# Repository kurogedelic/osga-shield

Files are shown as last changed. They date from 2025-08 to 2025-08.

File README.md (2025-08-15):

# osga-shield

mock

An open hardware platform for creative coding and generative art, designed to work with the [OSGA software platform](https://github.com/kurogedelic/osga).

## Project Structure

```
osga-shield/
├── CLAUDE.md              # Complete setup guide and troubleshooting
├── PROJECT_STRUCTURE.md   # Detailed project organization
├── firmware/              # Raspberry Pi OS configuration and software
│   ├── install.sh        # Complete installation script
│   ├── boot/             # Boot configuration files
│   ├── config/           # System configurations (ALSA, Grove I2C)
│   ├── scripts/          # Hardware initialization scripts
│   └── systemd/          # Auto-start service definitions
├── hardware/              # Hardware design files
│   ├── kicad/            # KiCad schematic and PCB layout
│   ├── bom/              # Bill of Materials
│   ├── fabrication/      # Gerber files for PCB manufacturing
│   └── 3d-models/        # 3D models for enclosure
└── README.md             # This file - project overview
```

📋 See [PROJECT_STRUCTURE.md](PROJECT_STRUCTURE.md) for detailed organization guide.  
🔧 See [CLAUDE.md](CLAUDE.md) for complete setup instructions and troubleshooting.

## Overview

osga-shield is a Raspberry Pi shield that provides a complete hardware interface for audio-visual creative applications. It features physical controls, motion sensing, environmental monitoring, and high-quality audio output.

## Hardware Architecture

```mermaid
graph TD
  RPI["RPi Zero 2 W"]

  subgraph INPUTS
    BTN_A["Button A"]
    BTN_B["Button B"]
    BTN_C["Button C"]
    BTN_R["Rotary Button"]
    ENC["Rotary Encoder"]
    MPU["MPU6050 (Gyro + Accel)"]
    BME["BME280 (Temp / Hum / Pressure)"]
  end

  subgraph OUTPUTS
    DISP["ILI9341 (320x240 SPI LCD)"]
    DAC["PCM5102 (I2S DAC)"]
    SPK["Speaker"]
    HAPTIC["Piezo Haptic"]
  end

  BTN_A --> RPI
  BTN_B --> RPI
  BTN_C --> RPI
  BTN_R --> RPI
  ENC --> RPI
  MPU --> RPI
  BME --> RPI

  RPI --> DISP
  RPI --> DAC
  DAC --> SPK
  RPI --> HAPTIC
```

## Specifications

### Display
- **Controller**: ILI9341
- **Resolution**: 320x240 pixels
- **Interface**: SPI
- **Color**: 16-bit RGB

### Audio
- **DAC**: PCM5102A (I2S)
- **Output**: 3.5mm stereo jack + built-in speaker
- **Sample Rate**: Up to 384kHz
- **Bit Depth**: 32-bit

### Input Controls
- **Buttons**: 2x tactile switches (A, B)
- **Rotary Encoder**: With push button function (Enter)
- **Motion**: MPU6050 6-axis IMU (3-axis gyro + 3-axis accelerometer)

### Expansion
- **Grove Connector**: I²C expansion port for additional sensors/modules
  - Compatible with Seeed Studio Grove ecosystem
  - 3.3V/5V power selectable

### Feedback
- **Haptic**: Piezo element for tactile feedback
- **Visual**: SPI LCD display

### Processing
- **Platform**: Raspberry Pi Zero 2 W
- **Connectivity**: WiFi, Bluetooth

## Pin Mapping (Raspberry Pi Zero 2 WH)

### I²C Buses
| Bus | Component | GPIO Pin | Physical Pin | Function |
|-----|---|---|---|---|
| I²C1 | MPU_SDA | GPIO 2 | Pin 3 | MPU6050 Data |
| I²C1 | MPU_SCL | GPIO 3 | Pin 5 | MPU6050 Clock |
| I²C (SW) | Grove_SDA | GPIO 22 | Pin 15 | Grove Connector Data |
| I²C (SW) | Grove_SCL | GPIO 23 | Pin 16 | Grove Connector Clock |

### Audio (I²S)
| Component | GPIO Pin | Physical Pin | Function |
|---|---|---|---|
| I2S_BCK | GPIO 18 | Pin 12 | Bit Clock |
| I2S_LRCK | GPIO 19 | Pin 35 | Left/Right Clock |
| I2S_IN | GPIO 20 | Pin 38 | Audio Input |
| I2S_OUT | GPIO 21 | Pin 40 | Audio Output (to PCM5102) |

### Display (SPI)
| Component | GPIO Pin | Physical Pin | Function |
|---|---|---|---|
| LCD_CS | GPIO 8 (CE0) | Pin 24 | Chip Select |
| LCD_MISO | GPIO 9 | Pin 21 | Master In Slave Out |
| LCD_MOSI | GPIO 10 | Pin 19 | Master Out Slave In |
| LCD_SCLK | GPIO 11 | Pin 23 | Serial Clock |
| LCD_DC | GPIO 24 | Pin 18 | Data/Command |
| LCD_RESET | GPIO 25 | Pin 22 | Reset |
| LCD_LED | GPIO 12 | Pin 32 | Backlight PWM |

### Input Controls
| Component | GPIO Pin | Physical Pin | Function |
|---|---|---|---|
| Button_A | GPIO 6 | Pin 31 | Button A |
| Button_B | GPIO 5 | Pin 29 | Button B |
| Rotary_CLK | GPIO 16 | Pin 36 | Encoder Clock |
| Rotary_DT | GPIO 13 | Pin 33 | Encoder Data |
| Rotary_Enter | GPIO 26 | Pin 37 | Encoder Button |

### UART (Debug)
| Component | GPIO Pin | Physical Pin | Function |
|---|---|---|---|
| UART_TX | GPIO 14 | Pin 8 | Transmit |
| UART_RX | GPIO 15 | Pin 10 | Receive |

## Software Support

The osga-shield is designed to work seamlessly with:
- **[OSGA](https://github.com/kurogedelic/osga)**: Open Sound & Graphics Appliance platform
- **Raspberry Pi OS**: Standard Linux support
- **Love2D**: For creative coding applications
- **Python**: Via GPIO and device libraries

## Getting Started

1. **Hardware Assembly**
   - Mount the shield on a Raspberry Pi Zero 2 W
   - Connect speaker or headphones to audio output
   - Power via micro USB

2. **Software Installation**
   ```bash
   # Flash Raspberry Pi OS Lite to SD card
   # Boot the Pi and clone this repository
   git clone https://github.com/kurogedelic/osga-shield.git
   cd osga-shield/firmware
   
   # Run installation script
   sudo ./install.sh
   
   # System will reboot and start OSGA automatically
   ```

3. **Test Hardware**
   - Run the hardware test app from OSGA launcher
   - Verify all buttons, encoder, and sensors work

## Development

### Creating Apps
See the [OSGA documentation](https://github.com/kurogedelic/osga#creating-an-app) for app development guidelines.

### Hardware Libraries
- **Python**: Use `RPi.GPIO`, `smbus2` for I2C devices
- **C/C++**: Use `wiringPi` or direct register access
- **Love2D**: Via OSGA's hardware abstraction layer

## License

This hardware design is open source. Schematics and PCB designs will be released under:
- **Hardware**: CERN Open Hardware License v2
- **Software**: LGPL v3 (matching OSGA platform)

## Credits

Designed by Leo Kuroshita from Hugelton Instruments (2025)

## Contributing

Contributions are welcome! Please submit issues and pull requests for:
- Hardware improvements
- Documentation updates
- Example projects
- Bug fixes

## Related Projects

- **[OSGA](https://github.com/kurogedelic/osga)**: The software platform
- **[osga-apps](https://github.com/kurogedelic/osga-apps)**: Community-contributed applications

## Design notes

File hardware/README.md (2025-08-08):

# OSGA Shield Hardware

## Directory Structure

- **kicad/** - KiCad project files (schematic, PCB layout)
- **bom/** - Bill of Materials and component specifications
- **fabrication/** - Gerber files and fabrication outputs
- **3d-models/** - 3D models for enclosure and mechanical design

## Hardware Revision

Current Version: v1.0

## License

Hardware designs are released under CERN Open Hardware License v2

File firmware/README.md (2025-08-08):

# OSGA Shield Firmware

## Directory Structure

- **boot/** - Raspberry Pi boot configuration files
- **config/** - System configuration files (ALSA, etc.)
- **scripts/** - Initialization and utility scripts  
- **systemd/** - SystemD service definitions
- **install.sh** - Main installation script

## Installation

1. Flash Raspberry Pi OS Lite to SD card
2. Clone this repository on the Pi
3. Run installation script:
   ```bash
   cd firmware
   sudo ./install.sh
   ```
4. Reboot

## Configuration

The system runs in headless mode with:
- Direct framebuffer access via DRM/KMS
- I2S audio output
- Automatic OSGA startup on boot
- No X11/desktop environment

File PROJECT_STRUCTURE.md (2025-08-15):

# OSGA Shield Project Structure

## Directory Organization

```
osga-shield/
├── CLAUDE.md                 # Setup documentation and troubleshooting guide
├── README.md                 # Project overview and pin mappings
├── PROJECT_STRUCTURE.md      # This file - project organization guide
├── firmware/                 # Raspberry Pi OS configuration and software
│   ├── README.md            # Firmware installation guide
│   ├── install.sh           # Complete installation script
│   ├── boot/                # Boot configuration files
│   │   ├── config.txt       # Hardware configuration for Pi
│   │   └── cmdline.txt      # Kernel command line parameters
│   ├── config/              # System configuration files
│   │   ├── asound.conf      # ALSA audio configuration for PCM5102
│   │   └── grove-i2c.conf   # Grove connector I2C bus settings
│   ├── scripts/             # System initialization scripts
│   │   ├── grove-i2c-setup.sh   # Software I2C setup for Grove
│   │   ├── osga-init.sh     # Hardware initialization script
│   │   └── osga-splash      # Boot splash screen script
│   └── systemd/             # SystemD service definitions
│       ├── osga.service     # Main OSGA auto-start service
│       └── osga-early.service   # Early boot display service
└── hardware/                # Hardware design files
    ├── README.md            # Hardware documentation
    ├── kicad/               # KiCad PCB design files
    │   ├── osga.kicad_pro   # Main project file
    │   ├── osga.kicad_sch   # Schematic design
    │   ├── osga.kicad_pcb   # PCB layout
    │   └── *.kicad_sym      # Symbol libraries
    ├── bom/                 # Bill of Materials
    ├── fabrication/         # Gerber files for PCB manufacturing
    └── 3d-models/           # 3D models for enclosure design
```

## Key Components

### Firmware (Software)
- **Raspberry Pi OS Lite** - Minimal OS without desktop environment
- **OSGA Runtime** - Creative coding platform via Love2D
- **SystemD Services** - Auto-start configuration
- **Hardware Drivers** - I2S audio, SPI display, I2C sensors

### Hardware Design
- **KiCad Project** - Complete PCB design files
- **Manufacturing Files** - Ready for PCB fabrication
- **Component Lists** - BOM for assembly

## Usage

### For Users (Installation)
1. Flash Raspberry Pi OS Lite to SD card
2. Clone this repository on the Pi
3. Run `firmware/install.sh` as root
4. System will auto-configure and start OSGA

### For Developers (Hardware)
1. Open `hardware/kicad/osga.kicad_pro` in KiCad
2. Modify schematic and PCB as needed
3. Export gerber files to `hardware/fabrication/`
4. Update BOM in `hardware/bom/`

### For Documentation
- **CLAUDE.md** - Complete setup guide and troubleshooting
- **README.md** - Quick overview and pin mappings
- **firmware/README.md** - Software installation details
- **hardware/README.md** - Hardware specifications

## Version Control
- All design files are version controlled
- KiCad libraries included in repository
- Firmware scripts tested on Raspberry Pi Zero 2 W
- Documentation updated with each hardware revision

## License
- **Hardware**: CERN Open Hardware License v2
- **Software**: LGPL v3 (matching OSGA platform)

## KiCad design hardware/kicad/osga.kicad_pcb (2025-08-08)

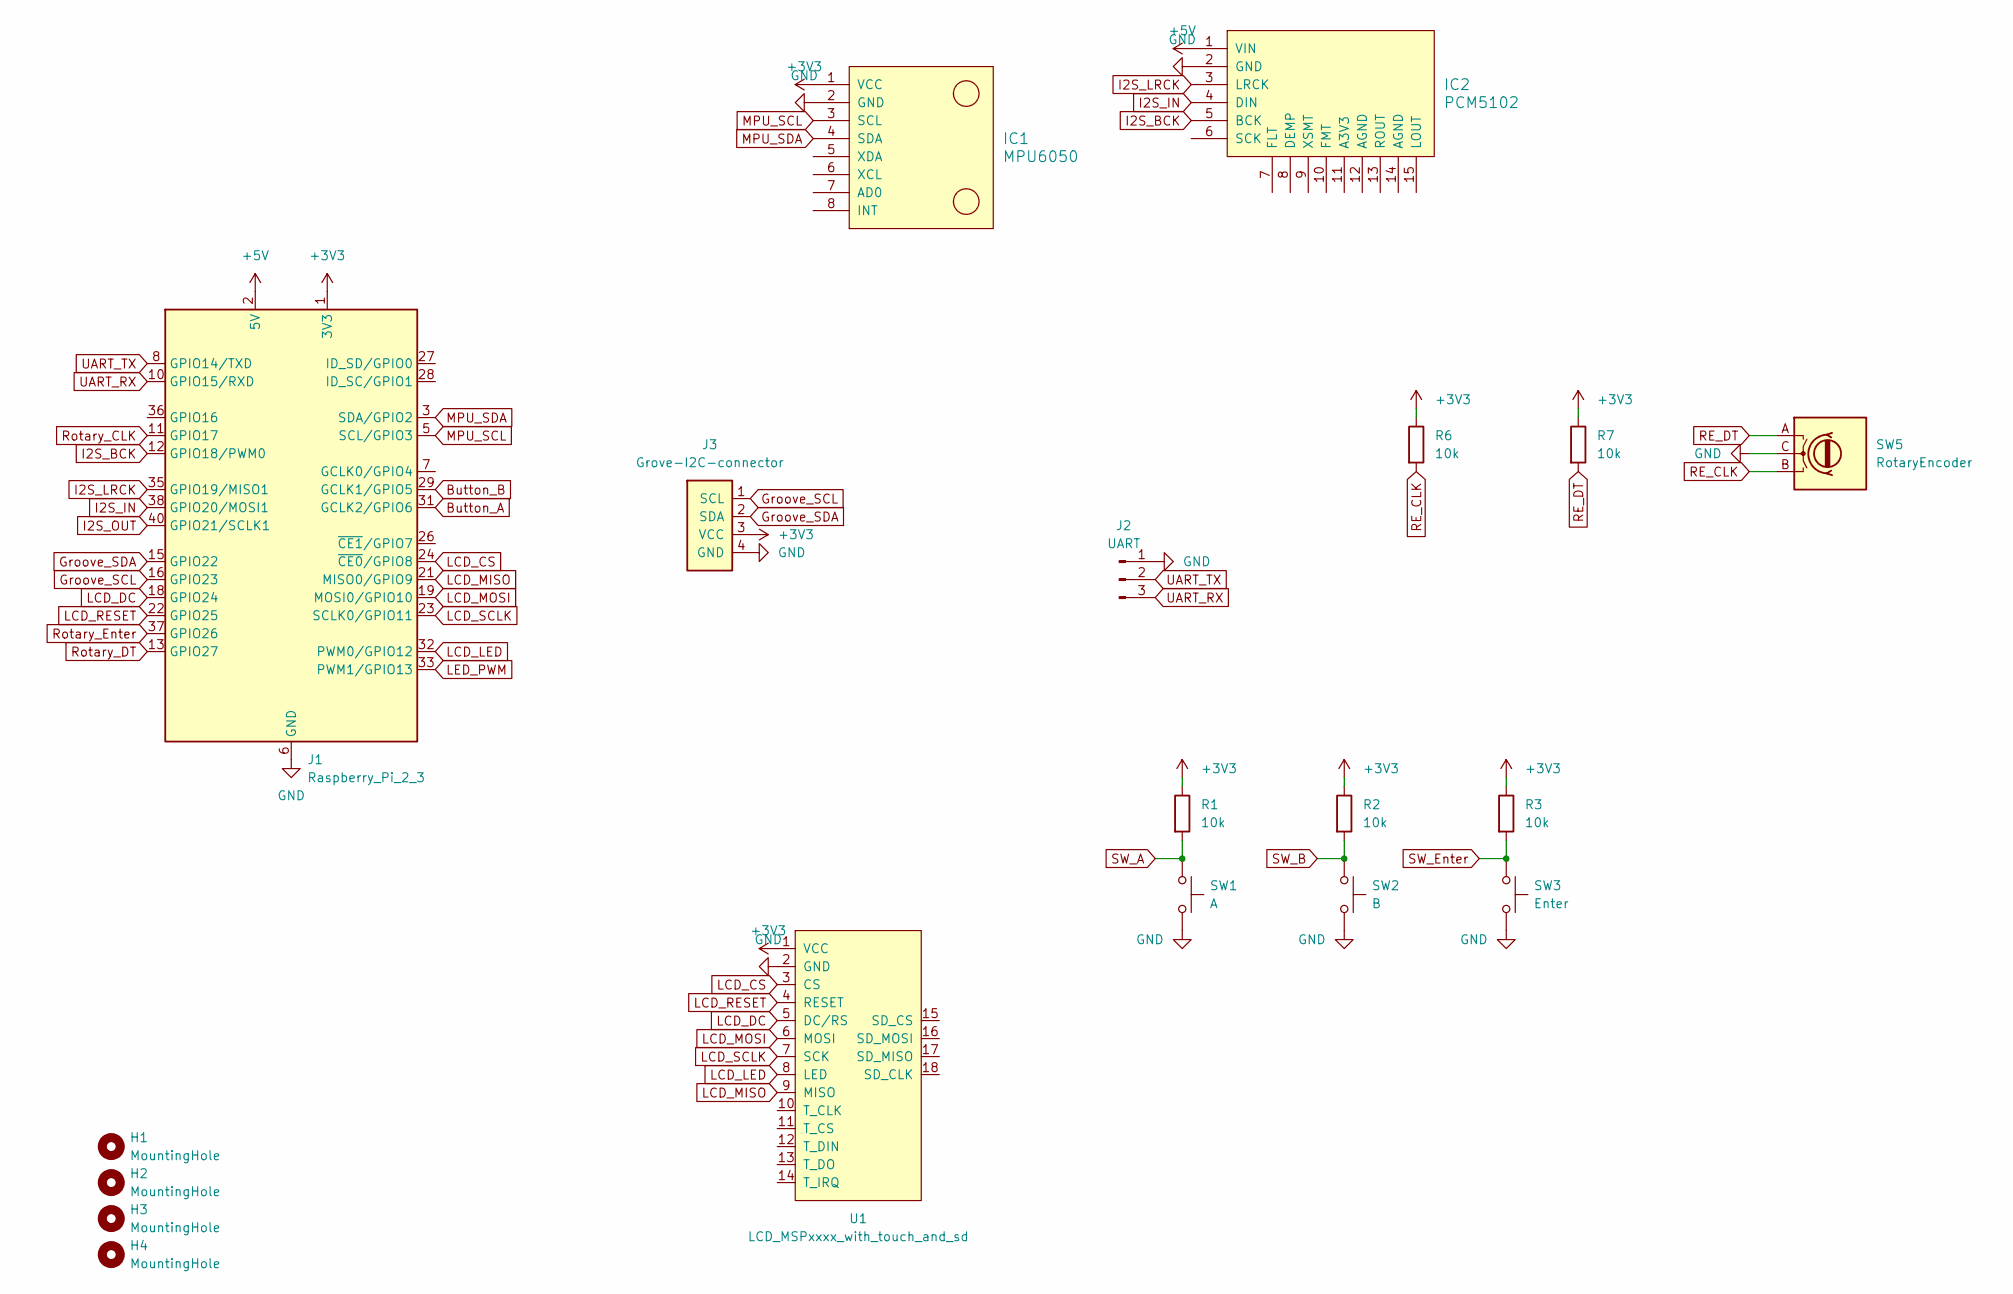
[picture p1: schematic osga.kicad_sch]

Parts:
H1, H2, H3, H4: MountingHole; Mounting_Wuerth_WA-SMSI-M2_H1mm_9774010243
IC1: MPU6050
IC2: PCM5102; PCM5102_flipped
J1: Raspberry_Pi_2_3; Raspberry_Pi_Header
J2: UART; PinSocket_1x03_P2.54mm_Horizontal
J3: Grove-I2C-connector; NS-Tech_Grove_1x04_P2mm_Vertical
R1, R2, R3, R6, R7: 10k; R_Axial_DIN0207_L6.3mm_D2.5mm_P10.16mm_Horizontal
SW1: A; SW_Redragon_LowProfile_PCB_1.00u
SW2: B; SW_Redragon_LowProfile_PCB_1.00u
SW3: Enter; SW_Redragon_LowProfile_PCB_1.00u
SW5: RotaryEncoder; RotaryEncoder_Alps_EC12E_Vertical_H20mm
U1: LCD_MSPxxxx_with_touch_and_sd; ili9341_2.4inch

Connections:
+3V3: IC1.1 (VCC), J1.1 (3V3), J1.17 (3V3), J3.3 (VCC), R1.1, R2.1, R3.1, R6.1, R7.1, U1.1 (VCC)
+5V: IC2.1 (VIN), J1.2 (5V), J1.4 (5V)
Button_A: J1.31 (GCLK2/GPIO6)
Button_B: J1.29 (GCLK1/GPIO5)
GND: IC1.2 (GND), IC2.2 (GND), J1.6 (GND), J1.9 (GND), J1.14 (GND), J1.20 (GND), J1.25 (GND), J1.30 (GND), J1.34 (GND), J1.39 (GND), J2.1, J3.4 (GND), SW1.2, SW2.2, SW3.2, SW5.C, U1.2 (GND)
Groove_SCL: J1.16 (GPIO23), J3.1 (SCL)
Groove_SDA: J1.15 (GPIO22), J3.2 (SDA)
I2S_BCK: IC2.5 (BCK), J1.12 (GPIO18/PWM0)
I2S_IN: IC2.4 (DIN), J1.38 (GPIO20/MOSI1)
I2S_LRCK: IC2.3 (LRCK), J1.35 (GPIO19/MISO1)
I2S_OUT: J1.40 (GPIO21/SCLK1)
LCD_CS: J1.24 (~CE0/GPIO8), U1.3 (CS)
LCD_DC: J1.18 (GPIO24), U1.5 (DC/RS)
LCD_LED: J1.32 (PWM0/GPIO12), U1.8 (LED)
LCD_MISO: J1.21 (MISO0/GPIO9), U1.9 (MISO)
LCD_MOSI: J1.19 (MOSI0/GPIO10), U1.6 (MOSI)
LCD_RESET: J1.22 (GPIO25), U1.4 (RESET)
LCD_SCLK: J1.23 (SCLK0/GPIO11), U1.7 (SCK)
LED_PWM: J1.33 (PWM1/GPIO13)
MPU_SCL: IC1.3 (SCL), J1.5 (SCL/GPIO3)
MPU_SDA: IC1.4 (SDA), J1.3 (SDA/GPIO2)
RE_CLK: R6.2, SW5.B
RE_DT: R7.2, SW5.A
Rotary_CLK: J1.11 (GPIO17)
Rotary_DT: J1.13 (GPIO27)
Rotary_Enter: J1.37 (GPIO26)
SW_A: R1.2, SW1.1
SW_B: R2.2, SW2.1
SW_Enter: R3.2, SW3.1
UART_RX: J1.10 (GPIO15/RXD), J2.3
UART_TX: J1.8 (GPIO14/TXD), J2.2

Board: 2 copper layers, 19 parts (2 on the bottom side), 24 nets, no tracks yet.

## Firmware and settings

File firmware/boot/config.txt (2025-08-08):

# OSGA Shield Boot Configuration
# Raspberry Pi Zero 2 W - Minimal Boot Setup

# GPU Memory (minimum needed for framebuffer)
gpu_mem=16

# Disable unnecessary interfaces
dtparam=audio=off
enable_uart=0

# Enable I2C1 for MPU6050
dtparam=i2c_arm=on
dtparam=i2c_baudrate=400000

# Software I2C for Grove connector (GPIO22/23)
# Will be configured via device tree overlay or bit-banging driver

# Enable SPI for display
dtparam=spi=on

# ILI9341 Display via DRM driver (native kernel support)
# Updated GPIO pins: reset:25, dc:24, cs:8, led:12
dtoverlay=fbtft,ili9341,rotate=90,speed=48000000,fps=60,gpios=reset:25,dc:24,cs:8,led:12

# Enable PWM for LCD backlight control
dtoverlay=pwm,pin=12,func=4

# I2S Audio for PCM5102
dtoverlay=hifiberry-dac

# Disable HDMI to save power
hdmi_blanking=2

# Disable Bluetooth to save power (optional)
dtoverlay=disable-bt

# Disable WiFi power management
dtparam=ant2=off

# Boot faster
boot_delay=0
disable_splash=1

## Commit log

2025-08-08 Organize project structure and add Raspberry Pi OS Lite boot configuration
    - Restructured project into firmware/ and hardware/ directories
    - Added systemd services for bare-metal OSGA startup
    - Configured direct framebuffer access via DRM/KMS (replacing fbcp-ili9341)
    - Added minimal boot configuration for Raspberry Pi OS Lite
    - Created installation script for automated setup
    - Updated README with new directory structure
    [config.txt]
2025-08-08 Update pin mapping for new hardware configuration
    - Reduced buttons from 3 to 2 (removed Button C)
    - Separated I2C buses: I2C1 for MPU6050, software I2C for Grove
    - Added Grove connector support with software I2C on GPIO22/23
    - Updated rotary encoder pins (CLK:16, DT:13, Enter:26)
    - Added full SPI pins for display including MISO
    - Added PWM control for LCD backlight on GPIO12
    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
    [config.txt, osga.kicad_pcb, osga.kicad_sch]
2025-08-15 Organize project structure and add comprehensive documentation
    - Enhanced .gitignore with comprehensive exclusions
    - Added CLAUDE.md with complete setup guide and troubleshooting
    - Added PROJECT_STRUCTURE.md with detailed organization
    - Updated README.md with improved project structure and documentation links
    - Reorganized documentation hierarchy for better navigation
    Documentation now provides:
    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
